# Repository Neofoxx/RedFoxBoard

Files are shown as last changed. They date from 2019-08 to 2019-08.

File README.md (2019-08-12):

# RedFoxBoard
A PIC32MX250 (and others) board, similar to the ubiquitous Blue Pill board

## Pinout
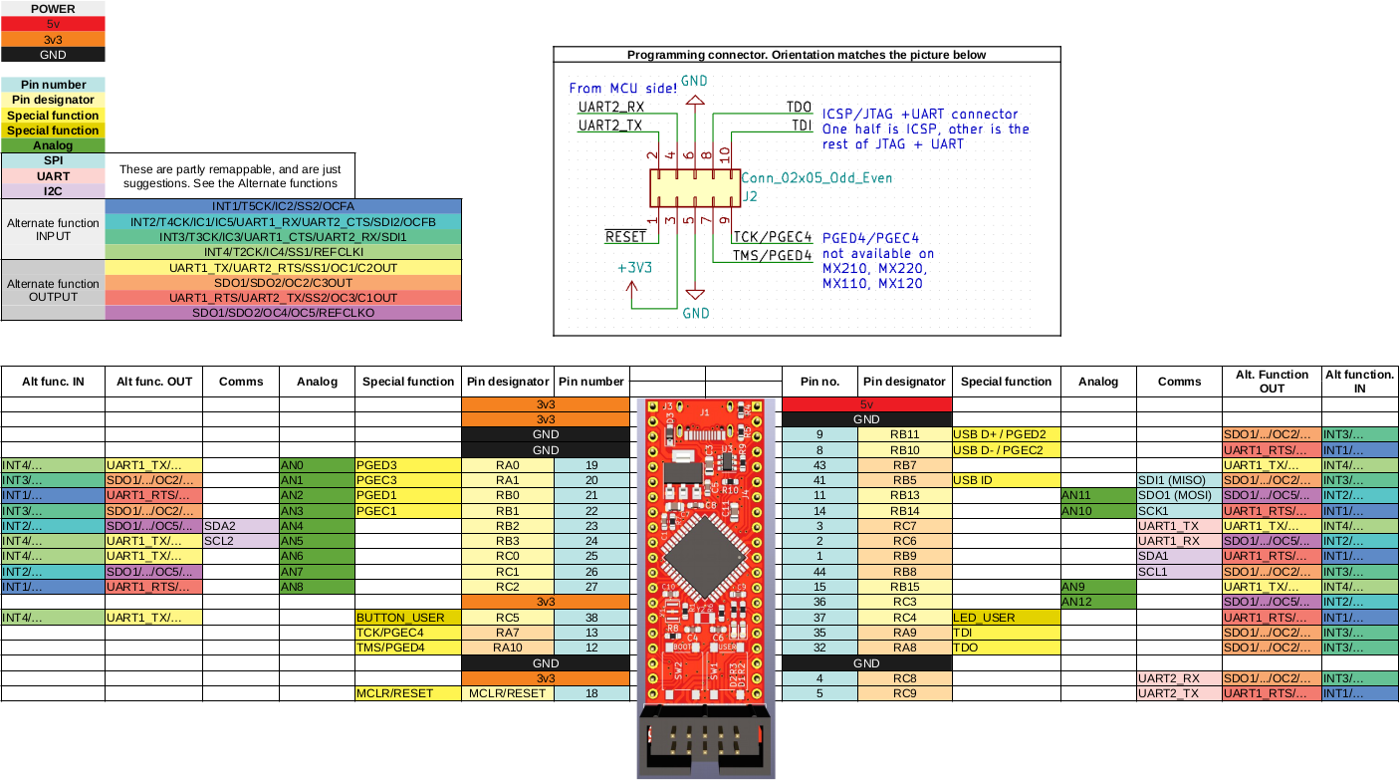
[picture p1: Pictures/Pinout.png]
Pinout

#### PCB view
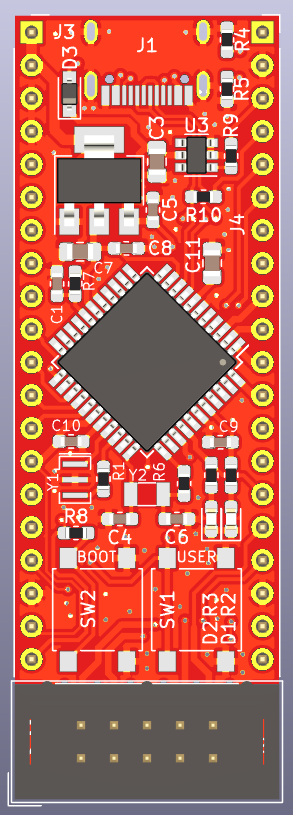
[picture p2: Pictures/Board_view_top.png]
PCB view TOP

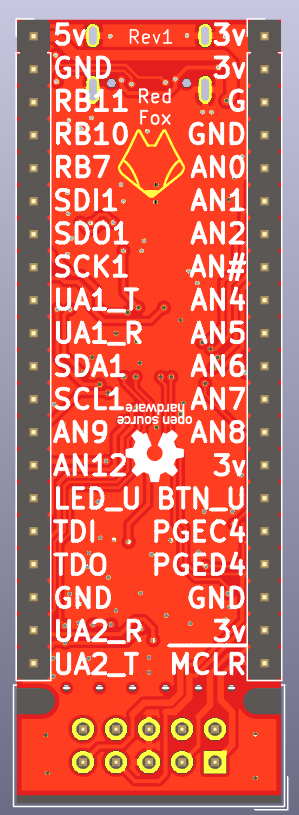
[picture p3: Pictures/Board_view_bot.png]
PCB view BOT

#### Panel view
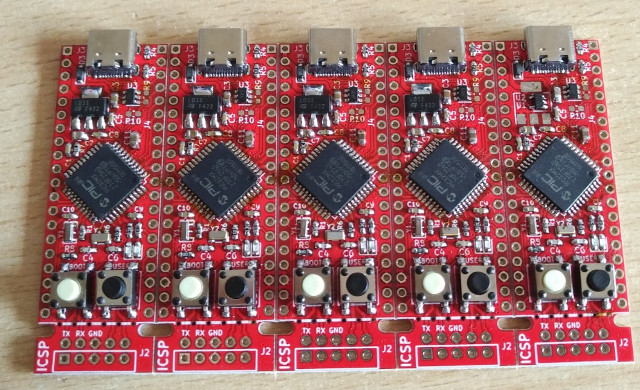
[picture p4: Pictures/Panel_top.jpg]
Panel view TOP

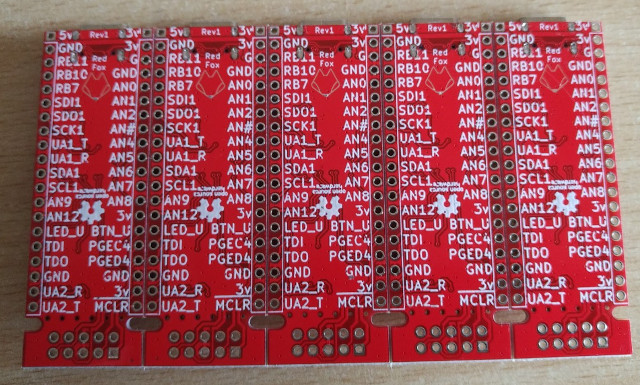
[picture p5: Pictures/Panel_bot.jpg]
Panel view BOT


## Description 

This is a small development board, featured around a PIC32MX microcontroller.

The intent is to have a small Blue Pill-like board, that can be quickly used with an open-source toolchain for the PIC32MX (see https://gitlab.com/rhn/pic32-parts-free )

The feature list is as follows:
- USB-C connector
- Two LEDs, one Power, one User
- Two buttons, one Reset, one User
- Components only on one side
- Footprints for two 3.3V regulators (smaller or bigger, depending on your needs)
- Fits into DIP-40 socket
- Breakaway section on the PCB, with place for an ICSP or JTAG connector

The purpose of the breakaway is to have a convenient place for programming/debugging. The same pins are also exposed on the side pins. To remove the breakaway, score the vias with a knife, then break it off.

Apart from the oscillator pins, everything is connected to the side pins.

If you do not wish to use USB functionality, you can place resistors R9 and R10, and connect those pins to the side as well.

### Supported MCUs
It supports the following microcontrollers:
- PIC32MX270F256D
- PIC32MX250F128D
- PIC32MX230F256D
- PIC32MX230F064D
- PIC32MX170F256D (without USB)
- PIC32MX150F128D (without USB)
- PIC32MX130F256D (without USB)
- PIC32MX130F064D (without USB)

Additionally, the following can also be used, but ICSP pins are not available on the provided header (use the ones on the side):
- PIC32MX220F032D
- PIC32MX210F016D
- PIC32MX120F032D (without USB)
- PIC32MX110F016D (without USB)

#### Notes

Please note, there are 6mm push buttons with different spacings on the pins. Make sure to get the right ones

The series resistor with the main oscillator hasn't been checked yet

The capacitors for the 32.768kHz crystal haven't been checked yet.

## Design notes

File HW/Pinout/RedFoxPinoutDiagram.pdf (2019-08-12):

Board pinout (ALL)

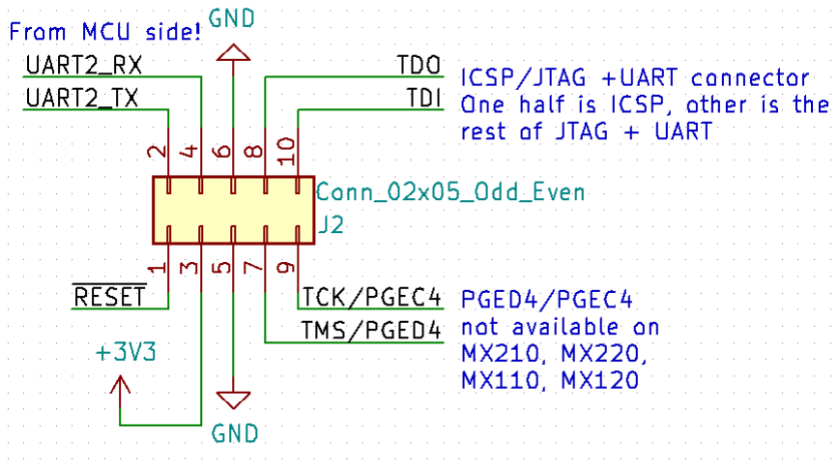
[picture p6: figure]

Page 1

POWER
5v
3v3
GND | Programming connector. Orientation matches the picture below

Pin number
Pin designator
Special function
Special function
Analog
SPI UART I2C | These are partly remappable, and are just suggestions. See the Alternate functions
Alternate function INPUT | INT1/T5CK/IC2/SS2/OCFA INT2/T4CK/IC1/IC5/UART1_RX/UART2_CTS/SDI2/OCFB INT3/T3CK/IC3/UART1_CTS/UART2_RX/SDI1 INT4/T2CK/IC4/SS1/REFCLKI
Alternate function OUTPUT | UART1_TX/UART2_RTS/SS1/OC1/C2OUT SDO1/SDO2/OC2/C3OUT UART1_RTS/UART2_TX/SS2/OC3/C1OUT SDO1/SDO2/OC4/OC5/REFCLKO
Alt func. IN | Alt func. OUT | Comms | Analog | Special function | Pin designator | Pin number | Pin no. | Pin designator | Special function | Analog | Comms | Alt. Function OUT | Alt function. IN
| | | | | 3v3 | | 5v
| | | | | 3v3 | | GND
| | | | | GND | | 9 | RB11 | USB D+ / PGED2 | | | SDO1/.../OC2/… | INT3/…
| | | | | GND | | 8 | RB10 | USB D- / PGEC2 | | | UART1_RTS/… | INT1/…
INT4/… | UART1_TX/… | | AN0 | PGED3 | RA0 | 19 | 43 | RB7 | | | | UART1_TX/… | INT4/…
INT3/… | SDO1/.../OC2/… | | AN1 | PGEC3 | RA1 | 20 | 41 | RB5 | USB ID | | SDI1 (MISO) | SDO1/.../OC2/… | INT3/…
INT1/… | UART1_RTS/… | | AN2 | PGED1 | RB0 | 21 | 11 | RB13 | | AN11 | SDO1 (MOSI) | SDO1/.../OC5/... | INT2/…
INT3/… | SDO1/.../OC2/… | | AN3 | PGEC1 | RB1 | 22 | 14 | RB14 | | AN10 | SCK1 | UART1_RTS/… | INT1/…
INT2/… | SDO1/.../OC5/... | SDA2 | AN4 | | RB2 | 23 | 3 | RC7 | | | UART1_TX | UART1_TX/… | INT4/…
INT4/… | UART1_TX/… | SCL2 | AN5 | | RB3 | 24 | 2 | RC6 | | | UART1_RX | SDO1/.../OC5/... | INT2/…
INT4/… | UART1_TX/… | | AN6 | | RC0 | 25 | 1 | RB9 | | | SDA1 | UART1_RTS/… | INT1/…
INT2/… | SDO1/.../OC5/... | | AN7 | | RC1 | 26 | 44 | RB8 | | | SCL1 | SDO1/.../OC2/… | INT3/…
INT1/… | UART1_RTS/… | | AN8 | | RC2 | 27 | 15 | RB15 | | AN9 | | UART1_TX/… | INT4/…
| | | | | 3v3 | | 36 | RC3 | | AN12 | | SDO1/.../OC5/... | INT2/…
INT4/… | UART1_TX/… | | | BUTTON_USER | RC5 | 38 | 37 | RC4 | LED_USER | | | UART1_RTS/… | INT1/…
| | | | TCK/PGEC4 | RA7 | 13 | 35 | RA9 | TDI | | | SDO1/.../OC2/… | INT3/…
| | | | TMS/PGED4 | RA10 | 12 | 32 | RA8 | TDO | | | SDO1/.../OC2/… | INT3/…
| | | | | GND | | GND
| | | | | 3v3 | | 4 | RC8 | | | UART2_RX | SDO1/.../OC2/… | INT3/…
| | | | MCLR/RESET | MCLR/RESET | 18 | 5 | RC9 | | | UART2_TX | UART1_RTS/… | INT1/…

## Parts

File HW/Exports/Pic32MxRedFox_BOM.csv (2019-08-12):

Source: | /home/neofoxx/Projects/HW/Gitted/RedFoxBoard/HW/Pic32MxRedFox.sch
Date: | pon 12 avg 2019 22:32:37 CEST
Tool: | Eeschema 5.0.2-bee76a0~70~ubuntu18.04.1
Generator: | /usr/share/kicad/plugins/bom_csv_grouped_by_value_with_fp.py
Component Count: | 42
Ref | Qnty | Value | Cmp name | Footprint | Description | Vendor
C3, C7, | 2 | 4u7 | C | Capacitor_SMD:C_0805_2012Metric_Pad1.15x1.40mm_HandSolder | Unpolarized capacitor
C4, C6, | 2 | 27pF | C | Capacitor_SMD:C_0603_1608Metric_Pad1.05x0.95mm_HandSolder | Unpolarized capacitor
C5, C8, C10, C9, C1, | 5 | 100nF | C | Capacitor_SMD:C_0603_1608Metric_Pad1.05x0.95mm_HandSolder | Unpolarized capacitor
C11, | 1 | 10uF | C | Capacitor_SMD:C_0805_2012Metric_Pad1.15x1.40mm_HandSolder | Unpolarized capacitor
D1, D2, | 2 | LED | LED | LED_SMD:LED_0603_1608Metric_Pad1.05x0.95mm_HandSolder | Light emitting diode
D3, | 1 | D_Schottky | D_Schottky | Diode_SMD:D_SOD-323_HandSoldering | Schottky diode
H1, H3, H5, H2, H4, H6, | 6 | MB_0.5 | MountingHole | KiCAD library:MouseBiteHole_0.5mm | Mounting Hole without connection
J1, | 1 | USB_C_Receptacle_USB2.0 | USB_C_Receptacle_USB2.0 | KiCAD library:Jing USB C 2.0 16pin receptable | USB 2.0-only Type-C Receptacle connector
J2, | 1 | Conn_02x05_Odd_Even | Conn_02x05_Odd_Even | Connector_IDC:IDC-Header_2x05_P2.54mm_Vertical | Generic connector, double row, 02x05, odd/even pin numbering scheme (row 1 odd numbers, row 2 even numbers), script generated (kicad-library-utils/schlib/autogen/connector/)
J3, J4, | 2 | Conn_01x20 | Conn_01x20 | Connector_PinHeader_2.54mm:PinHeader_1x20_P2.54mm_Vertical | Generic connector, single row, 01x20, script generated (kicad-library-utils/schlib/autogen/connector/)
MARK1, | 1 | LOGO | LOGO | KiCAD library:FOX_LOGO_MASK
R1, | 1 | 0R | R | Resistor_SMD:R_0603_1608Metric_Pad1.05x0.95mm_HandSolder | Resistor
R2, R3, | 2 | 1k | R | Resistor_SMD:R_0603_1608Metric_Pad1.05x0.95mm_HandSolder | Resistor
R4, R5, | 2 | 5k1 | R | Resistor_SMD:R_0603_1608Metric_Pad1.05x0.95mm_HandSolder | Resistor
R6, | 1 | 2k2 | R | Resistor_SMD:R_0603_1608Metric_Pad1.05x0.95mm_HandSolder | Resistor
R7, | 1 | 10k | R | Resistor_SMD:R_0603_1608Metric_Pad1.05x0.95mm_HandSolder | Resistor
R8, | 1 | 100R | R | Resistor_SMD:R_0603_1608Metric_Pad1.05x0.95mm_HandSolder | Resistor
R9, R10, | 2 | DNS | R | Resistor_SMD:R_0603_1608Metric_Pad1.05x0.95mm_HandSolder | Resistor
SW1, SW2, | 2 | SW_Push | SW_Push | Button_Switch_SMD:SW_SPST_B3S-1000 | Push button switch, generic, two pins
U1, | 1 | LD1117S33TR_SOT223 | LD1117S33TR_SOT223 | Package_TO_SOT_SMD:SOT-223-3_TabPin2 | 800mA Fixed Low Drop Positive Voltage Regulator, Fixed Output 3.3V, SOT-223
U2, | 1 | LN1134A332MR-G | AP2204K-3.3 | Package_TO_SOT_SMD:SOT-23-5 | 150mA low dropout linear regulator, wide input voltage range, 3.3V fixed positive output, SOT-23-5 package
U3, | 1 | SRV05-4 | SRV05-4 | Package_TO_SOT_SMD:SOT-23-6 | ESD Protection Diodes with Low Clamping Voltage, SOT-23-6
U4, | 1 | PIC32MX270F256D-IPT | PIC32MX270F256D-IPT | Package_QFP:TQFP-44_10x10mm_P0.8mm | 32-bit Microcontrollers (256KB Flash and 64KB SRAM TQFP-44) with Audio and Graphics Interfaces, USB, and Advanced Analog
Y1, | 1 | Crystal_GND2 | Crystal_GND2 | Crystal:Resonator_SMD_muRata_CSTxExxV-3Pin_3.0x1.1mm | Three pin crystal, GND on pin 2
Y2, | 1 | Crystal | Crystal | Crystal:Crystal_SMD_3215-2Pin_3.2x1.5mm | Two pin crystal

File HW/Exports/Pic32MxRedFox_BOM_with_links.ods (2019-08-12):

Source: | /home/neofoxx/Projects/HW/Gitted/RedFoxBoard/HW/Pic32MxRedFox.sch
Date: | pon 12 avg 2019 22:32:37 CEST
Tool: | Eeschema 5.0.2-bee76a0~70~ubuntu18.04.1
Generator: | /usr/share/kicad/plugins/bom_csv_grouped_by_value_with_fp.py
Component Count: | 42
Ref | Qnty | Value | Description | Link
C3, C7, | 2 | 4u7 | Capacitor, 0805 | https://lcsc.com/product-detail/Multilayer-Ceramic-Capacitors-MLCC-SMD-SMT_SAMSUNG_CL21A475KAQNNNE_4-7uF-475-10-25V_C1779.html
C4, C6, | 2 | 27pF | Capacitor, 0603 | https://lcsc.com/product-detail/Others_Murata-Electronics-GRM1885C1H270FA01D_C162215.html
C5, C8, C10, C9, C1, | 5 | 100nF | Capacitor, 0603 | https://lcsc.com/product-detail/Multilayer-Ceramic-Capacitors-MLCC-SMD-SMT_SAMSUNG_CL10B104KB8NNNC_100nF-104-10-50V_C1591.html
C11, | 1 | 10uF | Capacitor, 0805 | https://lcsc.com/product-detail/Others_Samsung-Electro-Mechanics-CL21A106KAYNNNF_C337995.html
D1, D2, | 2 | LED | LED, SMD, 0603 | Any LED, like https://lcsc.com/product-detail/Light-Emitting-Diodes-LED_Orange-SMDLED-100-180mcd_C84269.html
D3, | 1 | D_Schottky | Diode, schottky, SOD-323 | https://lcsc.com/product-detail/Schottky-Barrier-Diodes-SBD_SGP0230SD_C110406.html
J1, | 1 | USB_C_Receptacle_USB2.0 | USB-C connector | https://lcsc.com/product-detail/USB-Type-C_MC-311D_C136423.html
J2, | 1 | Conn_02x05_Odd_Even | Programming pin header | Any IDC 2x5 connector, or header pins, etc.
J3, J4, | 2 | Conn_01x20 | Side rails | Any pins, ets.
R1, | 1 | 0R | Resistor, 0603 | https://uk.farnell.com/multicomp/mcwr06x000-ptl/res-0r0-0-1w-jumper/dp/2447743
R2, R3, | 2 | 1k | Resistor, 0603 | https://lcsc.com/product-detail/Chip-Resistor-Surface-Mount_1KR-1001-1_C22548.html
R4, R5, | 2 | 5k1 | Resistor, 0603 | https://lcsc.com/product-detail/Chip-Resistor-Surface-Mount_5-1KR-5101-1_C105580.html
R6, | 1 | 2k2 | Resistor, 0603 | https://uk.farnell.com/te-connectivity/crgcq0603j2k2/res-2k2-5-0603-thick-film/dp/2861866
R7, | 1 | 10k | Resistor, 0603 | https://lcsc.com/product-detail/Chip-Resistor-Surface-Mount_10KR-1002-1_C98220.html
R8, | 1 | 100R | Resistor, 0603 | https://lcsc.com/product-detail/Chip-Resistor-Surface-Mount_100R-1000-1_C105588.html
R9, R10, | 2 | DNS | Resistor, 0603 | 0R if used
SW1, SW2, | 2 | SW_Push | SMD switch, 6mm | https://lcsc.com/product-detail/Tactile-Switches_C-K__C-K-C-K-Switch6-6-4-3_C225086.html
U1, | 1 | LD1117S33TR_SOT223 | Linear regulator (pick one) | Any LD1117 or others
U2, | 1 | LN1134A332MR-G | Linear regulator (pick one) | https://lcsc.com/product-detail/Low-Dropout-Regulators-LDO_NATLINEAR-LN1134A332MR-G_C141419.html
U3, | 1 | SRV05-4 | ESD diode | https://lcsc.com/product-detail/TVS_SRV05-4_C127538.html
U4, | 1 | PIC32MX270F256D-IPT | Microcontroller | https://uk.farnell.com/microchip/pic32mx270f256d-50i-pt/ic-32bit-mcu/dp/2449081
Y1, | 1 | Crystal_GND2 | 8MHz ceramic oscillator | https://lcsc.com/product-detail/Ceramic-Resonators_MuRata_CSTCE8M00G15C99-R0_8M-0-1-33pF_C110614.html
Y2, | 1 | Crystal | 32.768kHz crystal | https://lcsc.com/product-detail/SMD-Crystal-Resonators_Seiko_SC-32S32-768kHz20PPM12-5pF_Seiko-SC-32S32-768kHz20PPM12-5pF_C97606.html

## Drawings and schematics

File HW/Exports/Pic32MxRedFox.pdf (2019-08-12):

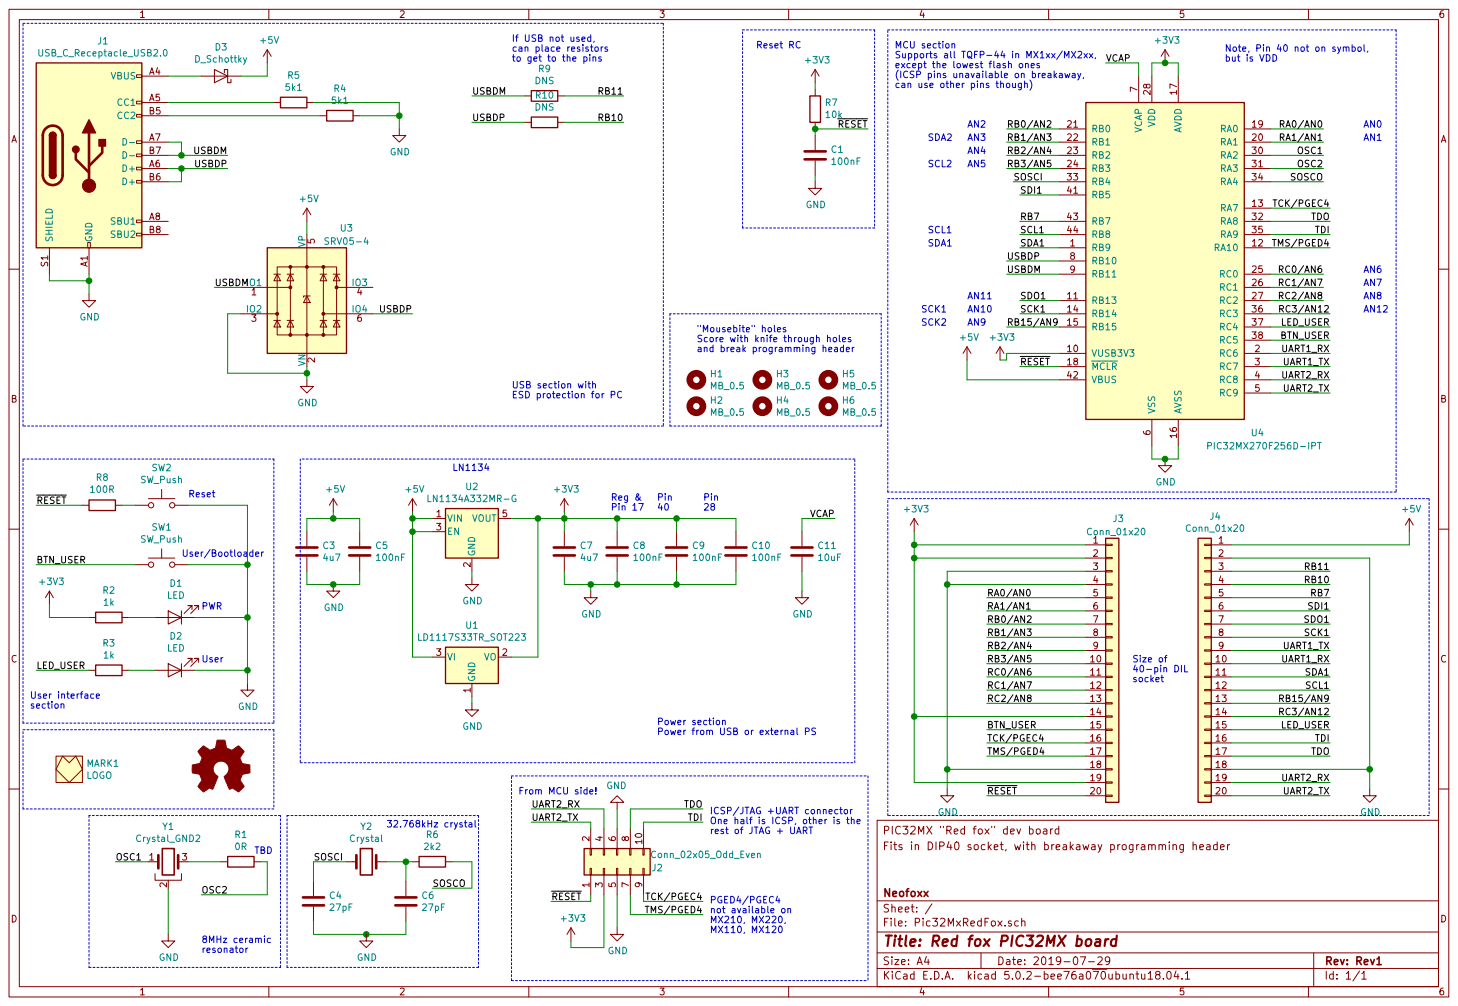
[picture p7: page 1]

If USB not used, can place resistors
to get to the pins
socket USBDP USBDM

MCU section Supports all TQFP-44 in MX1xx/MX2xx,

Note, Pin 40 not on symbol, but is VDD

except the lowest flash ones
(ICSP pins unavailable on breakaway,
can use other pins though)

7 RB10 8 RB11 9 VUSB3V3 10 RA1 20 RA2 30 RB13 11 RB0 21 RA3 31 RB5 41 RA10 12 RB1 22 RA8 32 VBUS 42 RA7 13 RB2 23 RB4 33 RB7 43 RB14 14 RB3 24 RA4 34 RB8 44 RB15 15 RC0 25 RA9 35 AVSS 16 RC1 26 RC3 36 AVDD 17 RC2 27 RC4 37 MCLR 18 VDD 28 RC5 38 RA0 19U4 PIC32MX270F256D-IPT SW1 SW_Push SW2 SW_PushD1

"Mousebite" holes Score with knife through holes

and break programming header MARK1

USB section with ESD protection for PC

Reset User/Bootloader PWR

GND

From MCU side! 32.768kHz crystal 8MHz ceramic

TMS/PGED4 TCK/PGEC4 TDI TDO

ICSP/JTAG +UART connector One half is ICSP, other is the

3 Y1 Crystal_GND2 R1 0R resonator | Y2 Crystal R6

rest of JTAG + UART RESET

Id: 1/1 Title: Red fox PIC32MX board

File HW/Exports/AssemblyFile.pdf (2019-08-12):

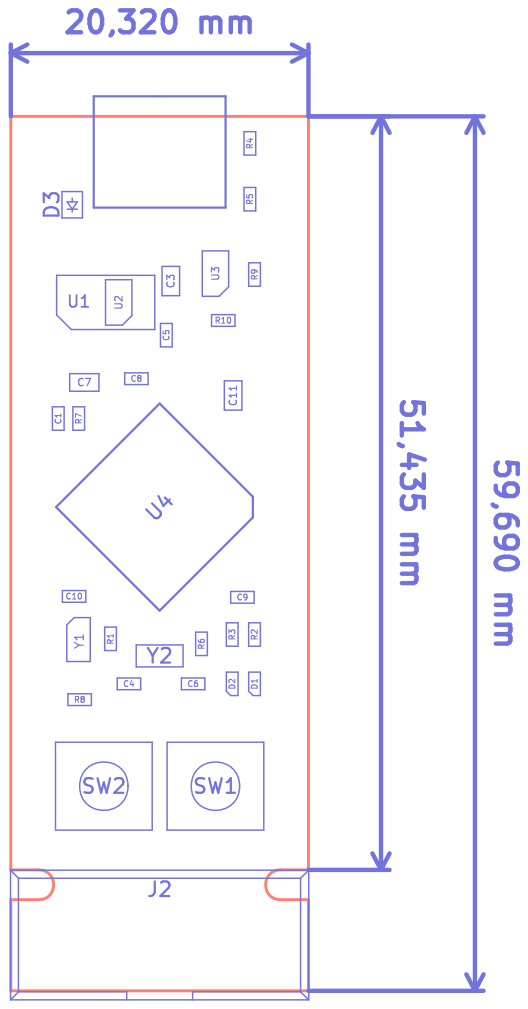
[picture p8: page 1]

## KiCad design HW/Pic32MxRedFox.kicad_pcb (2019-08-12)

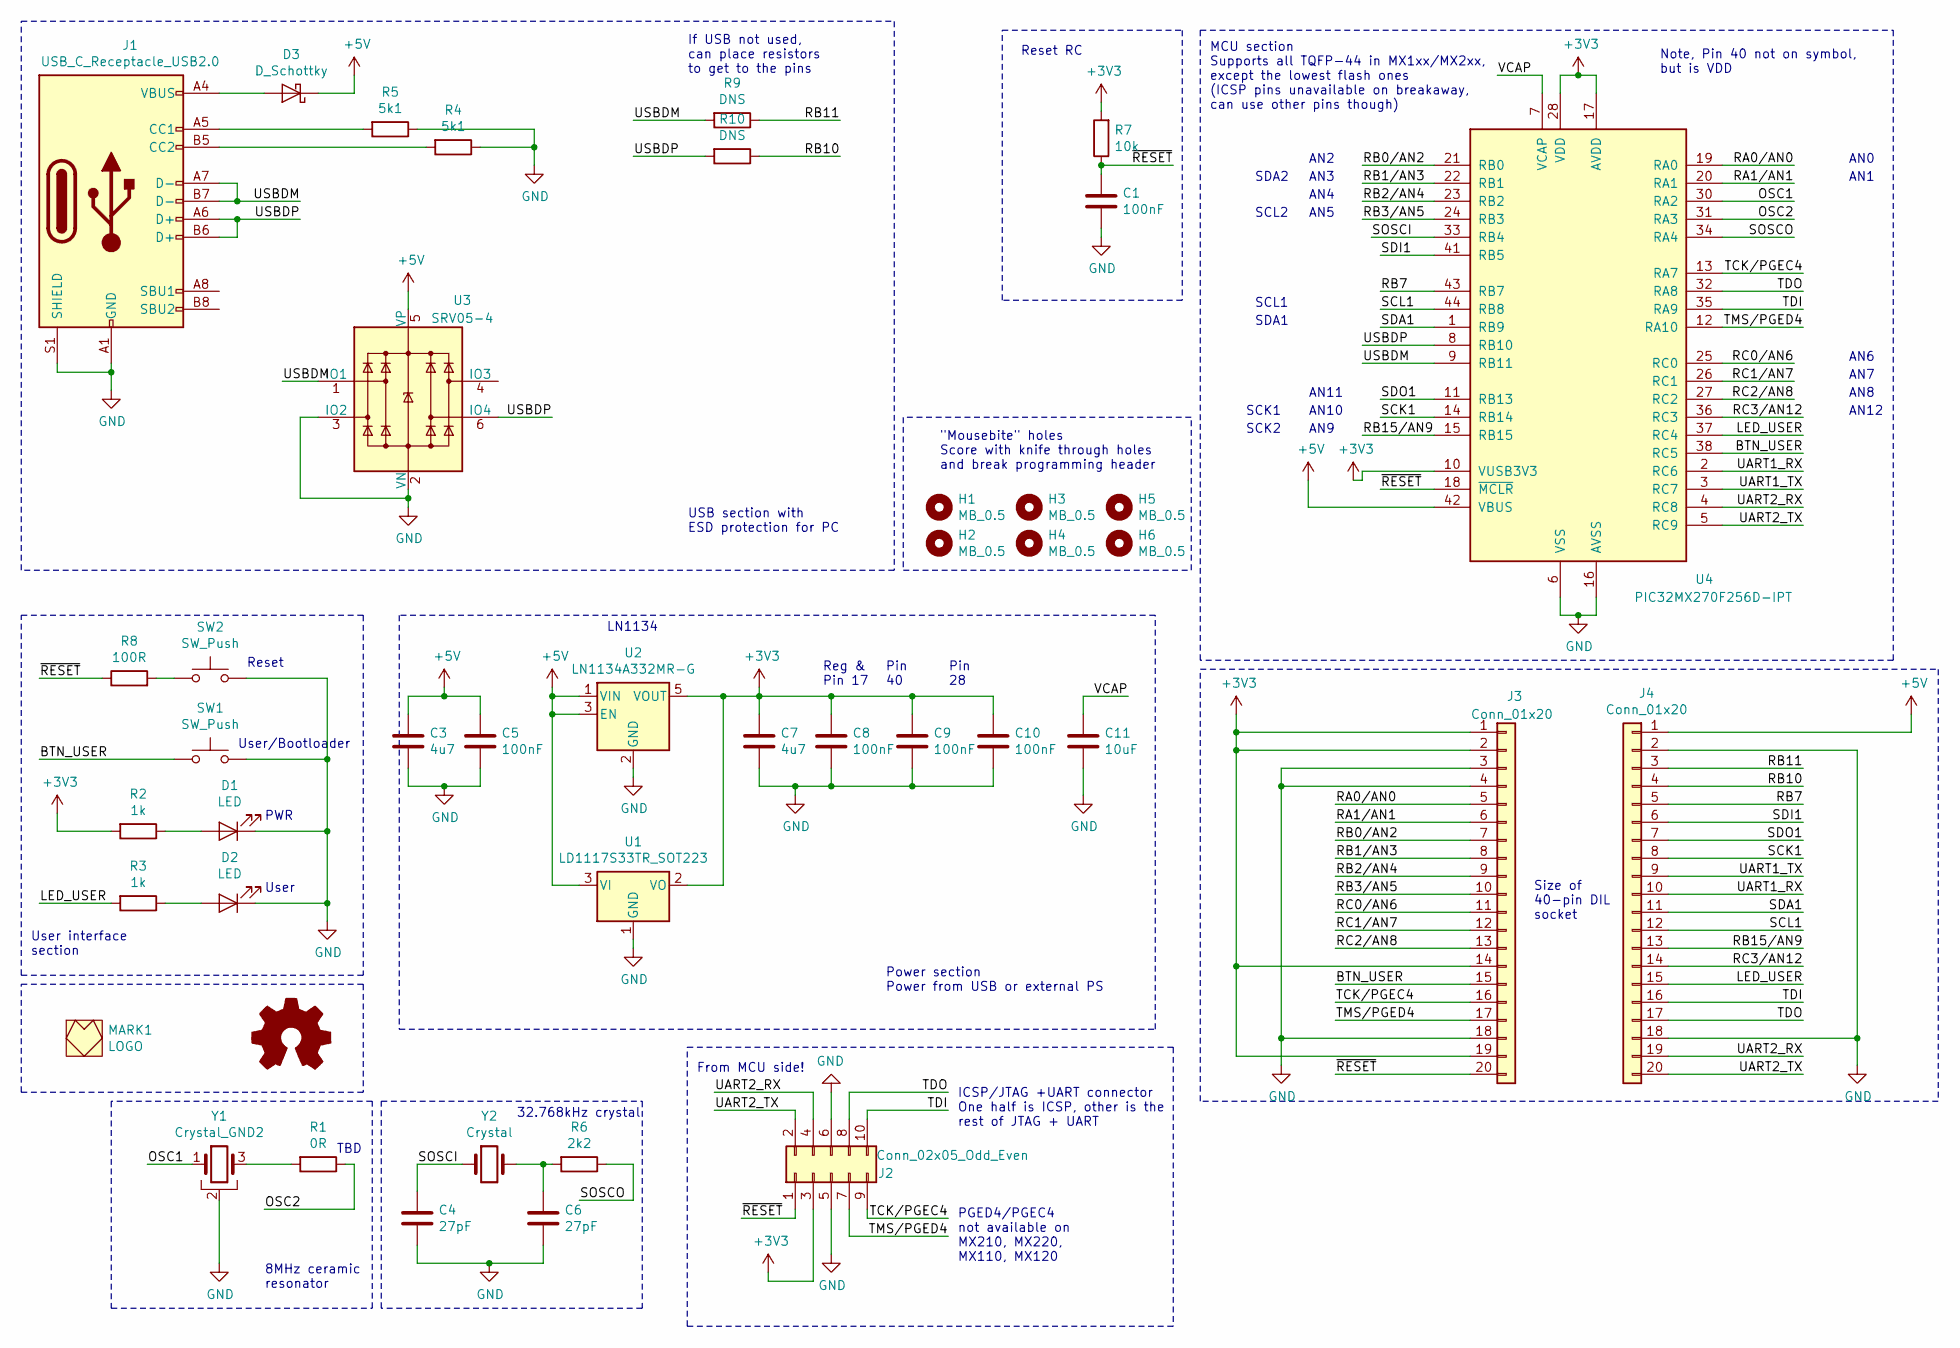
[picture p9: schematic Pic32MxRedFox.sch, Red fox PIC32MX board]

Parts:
C1, C5, C8, C9, C10: 100nF; C_0603_1608Metric_Pad1.05x0.95mm_HandSolder
C3, C7: 4u7; C_0805_2012Metric_Pad1.15x1.40mm_HandSolder
C4, C6: 27pF; C_0603_1608Metric_Pad1.05x0.95mm_HandSolder
C11: 10uF; C_0805_2012Metric_Pad1.15x1.40mm_HandSolder
D1, D2: LED; LED_0603_1608Metric_Pad1.05x0.95mm_HandSolder
D3: D_Schottky; D_SOD-323_HandSoldering
H1, H2, H3, H4, H5, H6: MB_0.5; MouseBiteHole_0.5mm
J1: USB_C_Receptacle_USB2.0; Jing USB C 2.0 16pin receptable
J2: Conn_02x05_Odd_Even; IDC-Header_2x05_P2.54mm_Vertical
J3, J4: Conn_01x20; PinHeader_1x20_P2.54mm_Vertical
MARK1: LOGO; FOX_LOGO_MASK
R1: 0R; R_0603_1608Metric_Pad1.05x0.95mm_HandSolder
R2, R3: 1k; R_0603_1608Metric_Pad1.05x0.95mm_HandSolder
R4, R5: 5k1; R_0603_1608Metric_Pad1.05x0.95mm_HandSolder
R6: 2k2; R_0603_1608Metric_Pad1.05x0.95mm_HandSolder
R7: 10k; R_0603_1608Metric_Pad1.05x0.95mm_HandSolder
R8: 100R; R_0603_1608Metric_Pad1.05x0.95mm_HandSolder
R9, R10: DNS; R_0603_1608Metric_Pad1.05x0.95mm_HandSolder
SW1, SW2: SW_Push; SW_SPST_B3S-1000
U1: LD1117S33TR_SOT223; SOT-223-3_TabPin2
U2: LN1134A332MR-G; SOT-23-5
U3: SRV05-4; SOT-23-6
U4: PIC32MX270F256D-IPT; TQFP-44_10x10mm_P0.8mm
Y1: Crystal_GND2; Resonator_SMD_muRata_CSTxExxV-3Pin_3.0x1.1mm
Y2: Crystal; Crystal_SMD_3215-2Pin_3.2x1.5mm

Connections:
+3V3: C7.1, C8.1, C9.1, C10.1, J2.3, J3.1, J3.2, J3.14, J3.19, R2.2, R7.2, U1.2 (VO), U2.5 (VOUT), U4.10 (VUSB3V3), U4.17 (AVDD), U4.28 (VDD), U4.40 (VDD)
+5V: C3.1, C5.1, D3.1 (K), J4.1, U1.3 (VI), U2.1 (VIN), U2.3 (EN), U3.5 (VP), U4.42 (VBUS)
/BTN_USER: J3.15, SW1.1, U4.38 (RC5)
/LED_USER: J4.15, R3.2, U4.37 (RC4)
/OSC1: U4.30 (RA2), Y1.1
/OSC2: R1.1, U4.31 (RA3)
/RA0/AN0: J3.5, U4.19 (RA0)
/RA1/AN1: J3.6, U4.20 (RA1)
/RB0/AN2: J3.7, U4.21 (RB0)
/RB1/AN3: J3.8, U4.22 (RB1)
/RB2/AN4: J3.9, U4.23 (RB2)
/RB3/AN5: J3.10, U4.24 (RB3)
/RB7: J4.5, U4.43 (RB7)
/RB10: J4.4, R10.1
/RB11: J4.3, R9.1
/RB15/AN9: J4.13, U4.15 (RB15)
/RC0/AN6: J3.11, U4.25 (RC0)
/RC1/AN7: J3.12, U4.26 (RC1)
/RC2/AN8: J3.13, U4.27 (RC2)
/RC3/AN12: J4.14, U4.36 (RC3)
/SCK1: J4.8, U4.14 (RB14)
/SCL1: J4.12, U4.44 (RB8)
/SDA1: J4.11, U4.1 (RB9)
/SDI1: J4.6, U4.41 (RB5)
/SDO1: J4.7, U4.11 (RB13)
/SOSCI: C4.1, U4.33 (RB4), Y2.1
/SOSCO: R6.1, U4.34 (RA4)
/TCK/PGEC4: J2.9, J3.16, U4.13 (RA7)
/TDI: J2.10, J4.16, U4.35 (RA9)
/TDO: J2.8, J4.17, U4.32 (RA8)
/TMS/PGED4: J2.7, J3.17, U4.12 (RA10)
/UART1_RX: J4.10, U4.2 (RC6)
/UART1_TX: J4.9, U4.3 (RC7)
/UART2_RX: J2.4, J4.19, U4.4 (RC8)
/UART2_TX: J2.2, J4.20, U4.5 (RC9)
/USBDM: J1.A7 (D-), J1.B7 (D-), R9.2, U3.1 (IO1), U4.9 (RB11)
/USBDP: J1.A6 (D+), J1.B6 (D+), R10.2, U3.6 (IO4), U4.8 (RB10)
/VCAP: C11.1, U4.7 (VCAP)
/~RESET~: C1.1, J2.1, J3.20, R7.1, R8.1, U4.18 (~MCLR)
GND: C1.2, C3.2, C4.2, C5.2, C6.2, C7.2, C8.2, C9.2, C10.2, C11.2, D1.1 (K), D2.1 (K), J1.A1 (GND), J1.A12 (GND), J1.B1 (GND), J1.B12 (GND), J1.S1 (SHIELD), J2.5, J2.6, J3.3, J3.4, J3.18, J4.2, J4.18, R4.1, R5.1, SW1.2, SW2.2, U1.1 (GND), U2.2 (GND), U3.2 (VN), U3.3 (IO2), U4.6 (VSS), U4.16 (AVSS), U4.29 (VSS), U4.39 (VSS), Y1.2
unnamed: C6.1, R6.2, Y2.2
unnamed: D1.2 (A), R2.1
unnamed: D2.2 (A), R3.1
unnamed: D3.2 (A), J1.A4 (VBUS), J1.A9 (VBUS), J1.B4 (VBUS), J1.B9 (VBUS)
unnamed: J1.A5 (CC1), R5.2
unnamed: J1.B5 (CC2), R4.2
unnamed: R1.2, Y1.3
unnamed: R8.2, SW2.1

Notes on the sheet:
Reset
User/Bootloader
PWR
User
Size of 40-pin DIL socket
ICSP/JTAG +UART connector One half is ICSP, other is the rest of JTAG + UART
From MCU side!
32.768kHz crystal
8MHz ceramic resonator
Reg & Pin 17
Pin 28
PGED4/PGEC4 not available on MX210, MX220, MX110, MX120
AN0
AN1
AN2
AN3
AN4
AN5
AN6
AN7
AN8
AN9
AN10
AN11
AN12
SDA1
SDA2
SCK1
SCK2
SCL1
SCL2
LN1134
TBD
Pin 40
If USB not used, can place resistors to get to the pins
User interface section
Power section Power from USB or external PS
MCU section Supports all TQFP-44 in MX1xx/MX2xx, except the lowest flash ones (ICSP pins unavailable on breakaway, can use other pins though)
Note, Pin 40 not on symbol, but is VDD
Reset RC

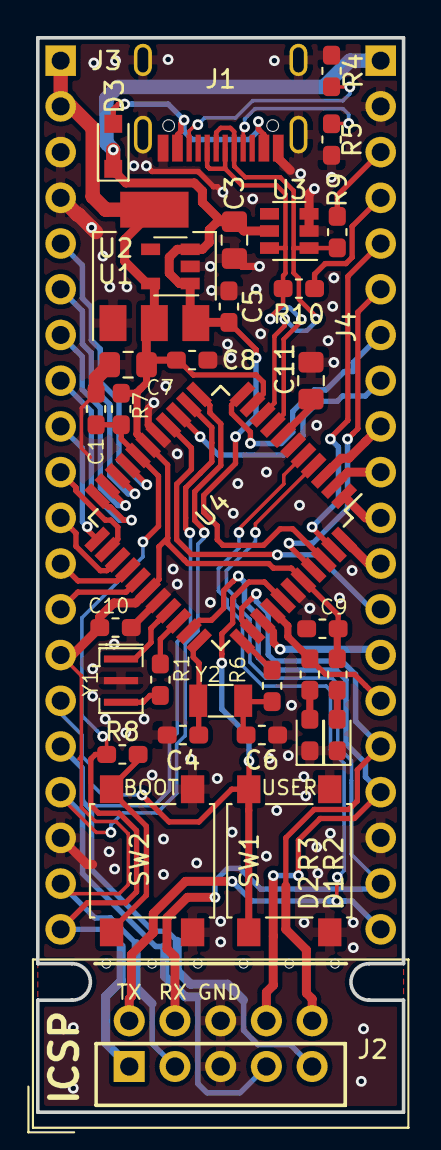
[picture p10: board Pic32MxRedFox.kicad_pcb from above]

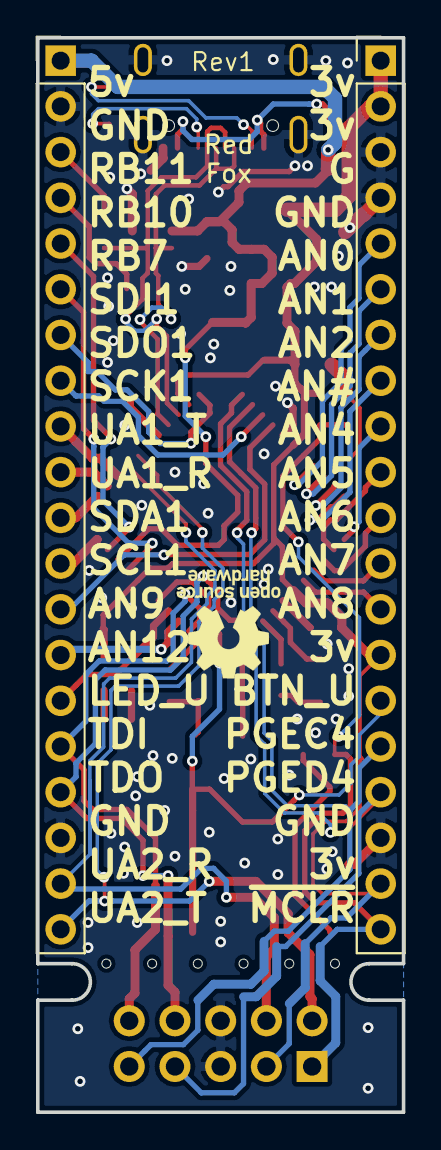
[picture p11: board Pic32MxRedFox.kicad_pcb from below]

Board: 2 copper layers, 20.3 x 59.7 mm, 42 parts (3 on the bottom side), 48 nets.
